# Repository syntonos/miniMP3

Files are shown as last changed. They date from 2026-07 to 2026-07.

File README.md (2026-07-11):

# miniMP3
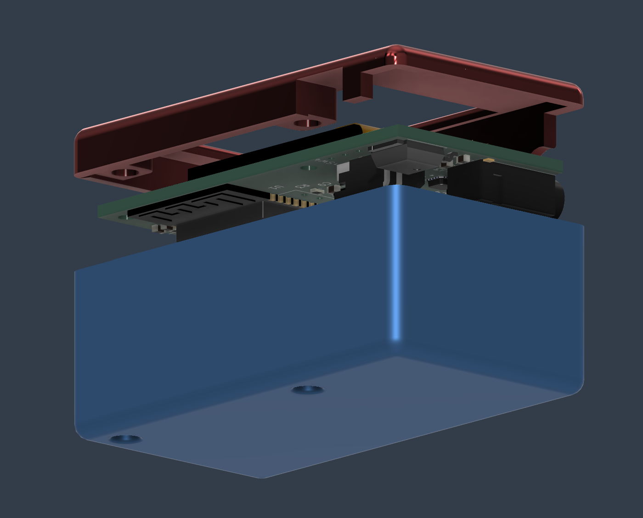
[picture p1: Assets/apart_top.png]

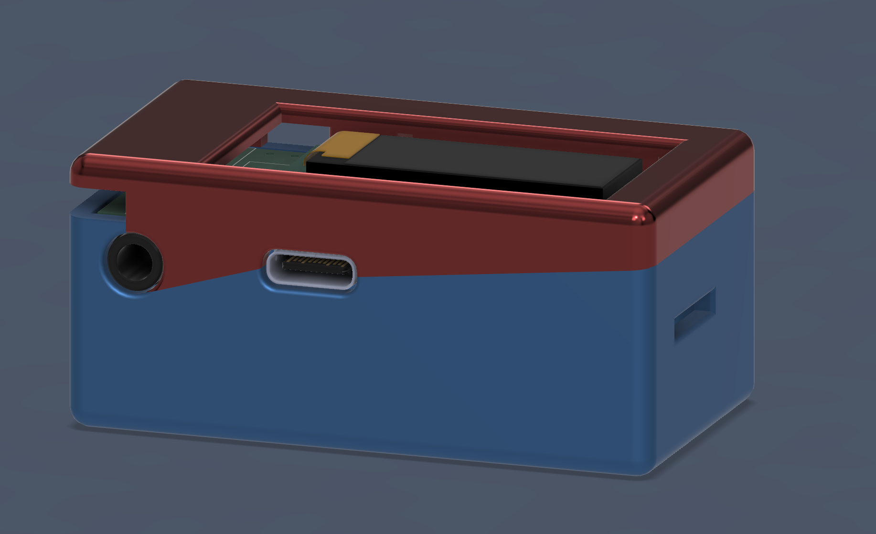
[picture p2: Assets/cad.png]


## About
A compact music player. 59.3 x 32 x 27 (mm). Bluetooth and 3.5mm jack compatible. mp3, wav, and flac compatible. 5-band EQ, and more functions when the firmware updates. 

## Idea
I wanted a little mp3 player that was small enough that I could just toss into my shirt pocket or keep it on a necklace. I don't want to be tied so much to my phone, and this seems like a reasonable first step to move a function off. There are also a couple old cds and etc. that I'd like to download.

## Assembly
Solder on:
- the display module
- the SD card module
- the boot switch (4x4 push switch)
- the power switch (toggle switch)
- the rotary switches

Plug in the LiPo Battery (JST-PH 2.0mm).

Insert the heat-sets into the two slots above and below. 


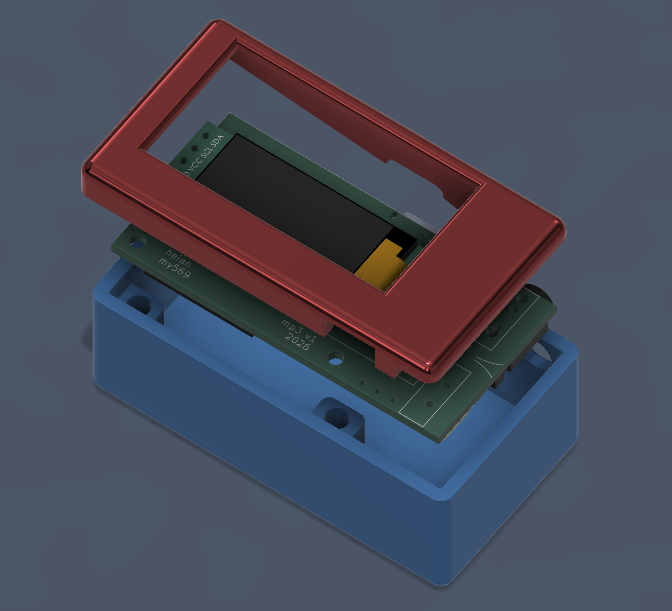
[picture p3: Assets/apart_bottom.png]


Fasten in the M2 screw on the bottom. 

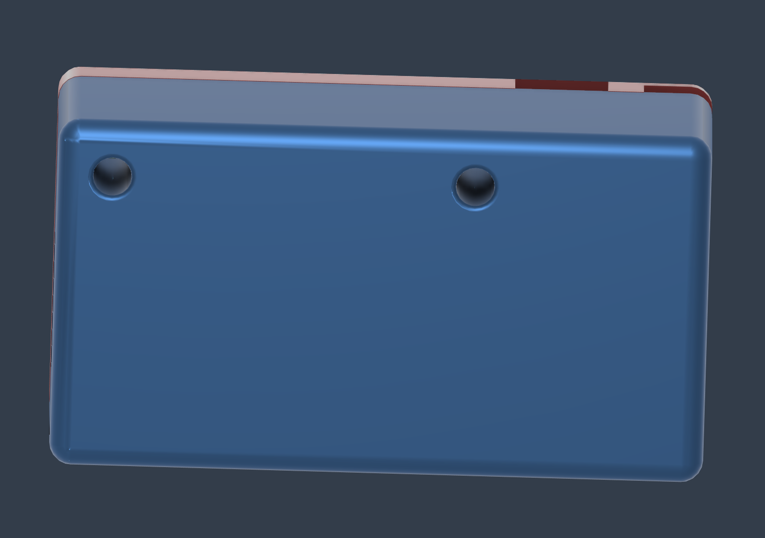
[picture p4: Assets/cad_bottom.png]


## PCB
### Layer 1 - Signal
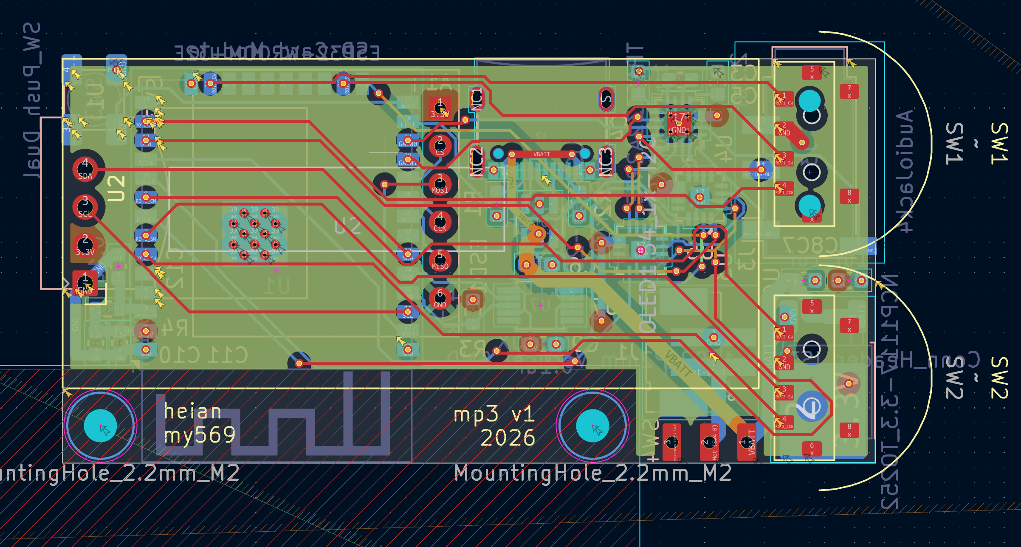
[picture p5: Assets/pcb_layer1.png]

### Layer 2 - GND
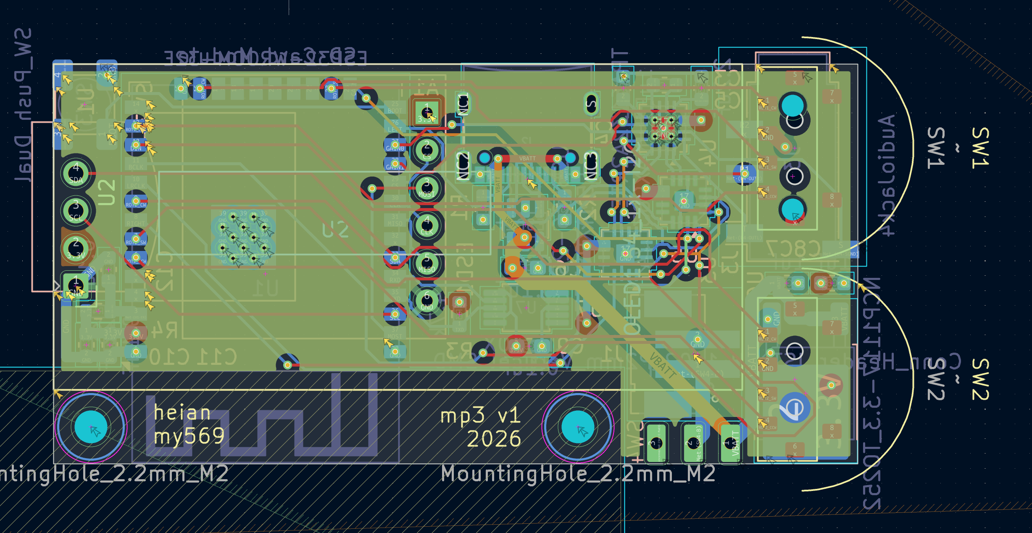
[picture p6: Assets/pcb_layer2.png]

### Layer 3 - Power
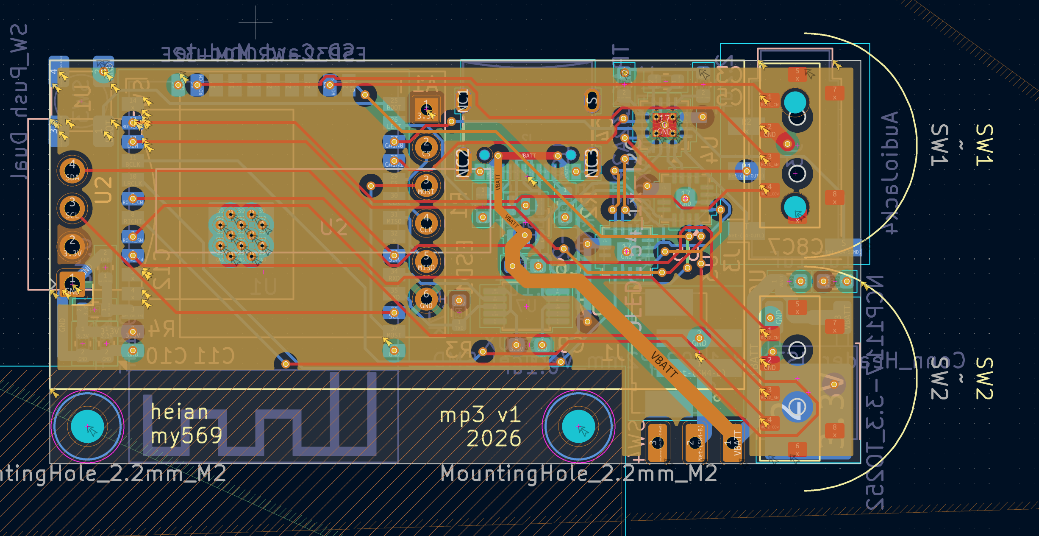
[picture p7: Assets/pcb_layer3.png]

### Layer 4 - Signal
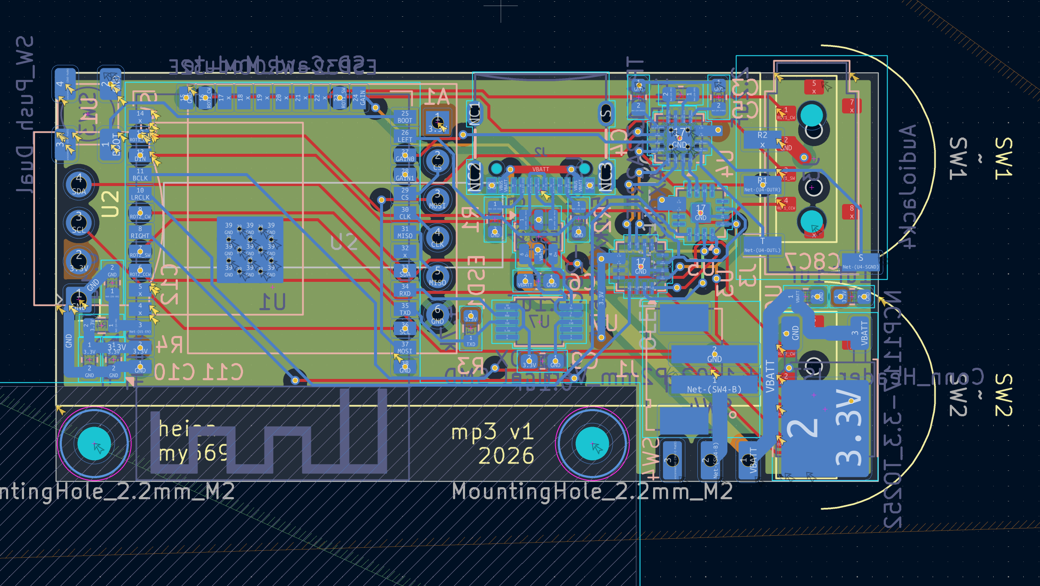
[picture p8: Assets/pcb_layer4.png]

### 3D Model Front
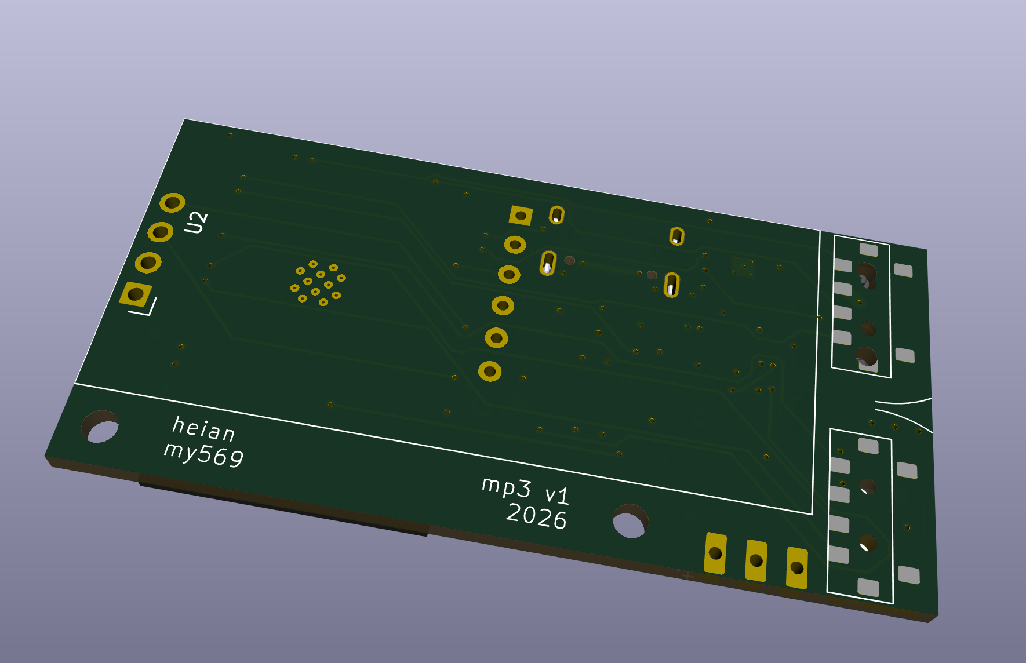
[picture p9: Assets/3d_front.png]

### 3D Model Back
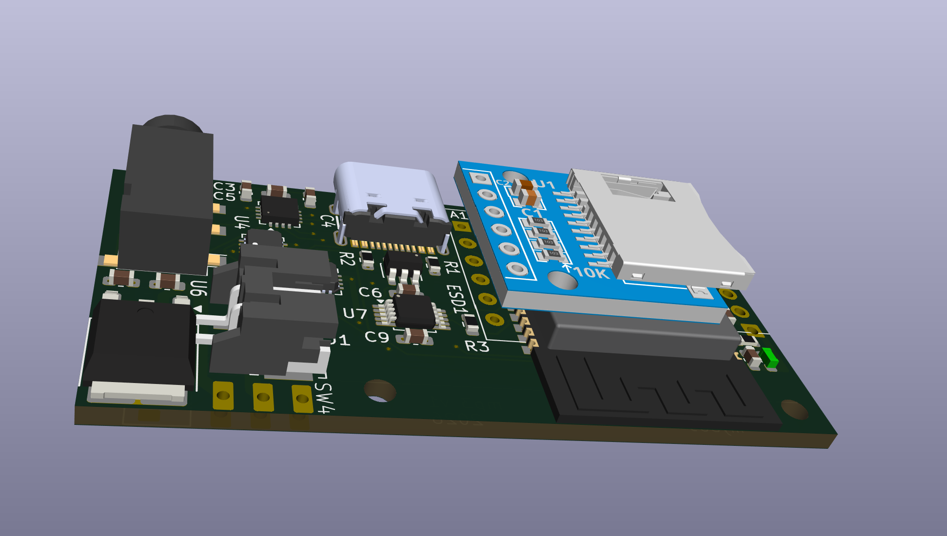
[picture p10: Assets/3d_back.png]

## Schematic
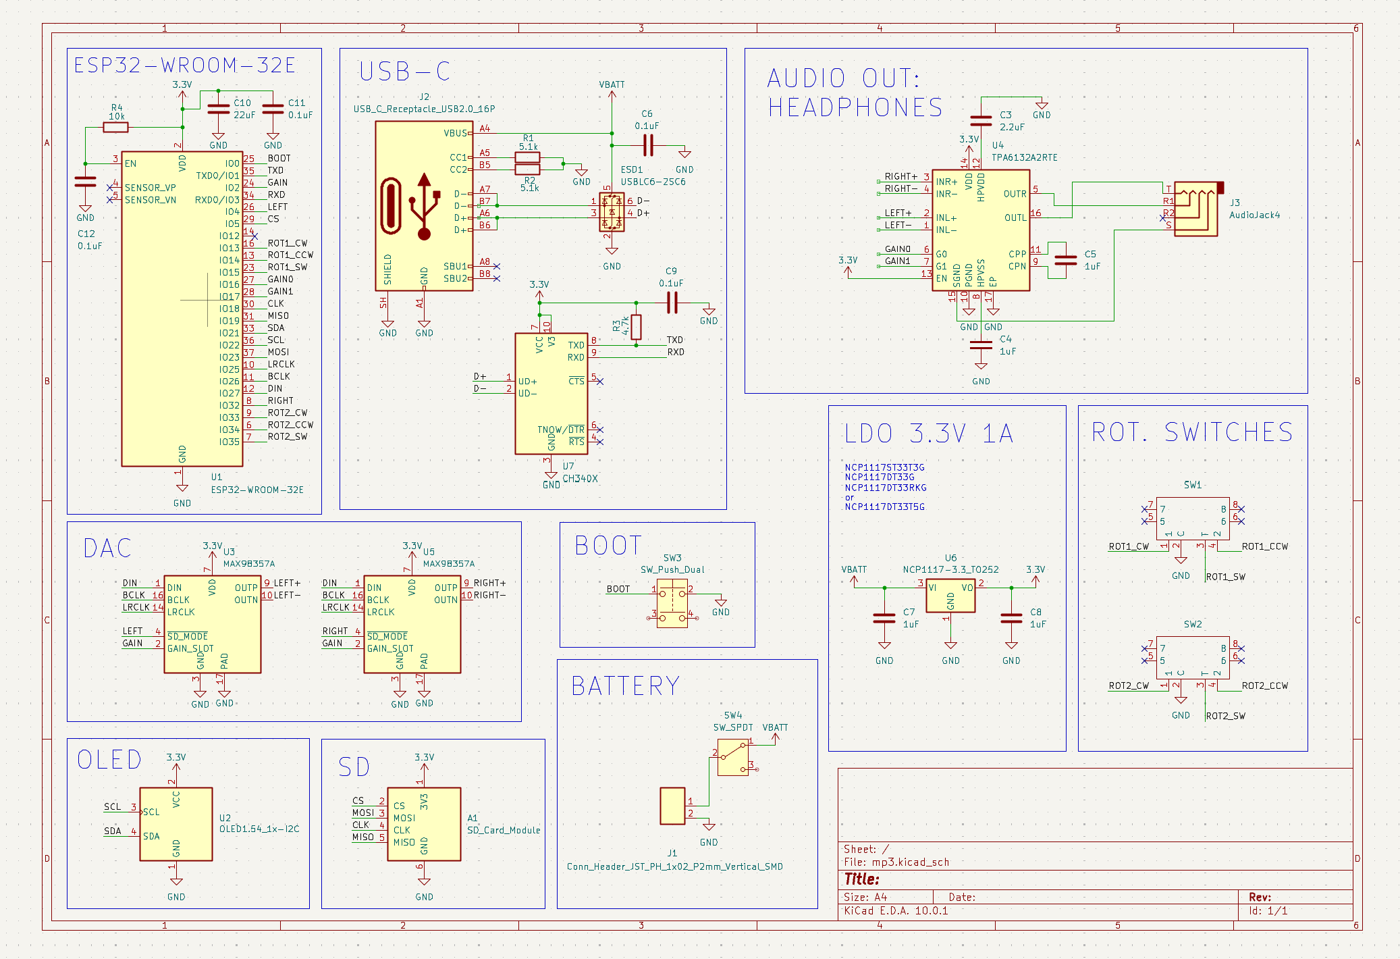
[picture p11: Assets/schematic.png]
 
## CAD

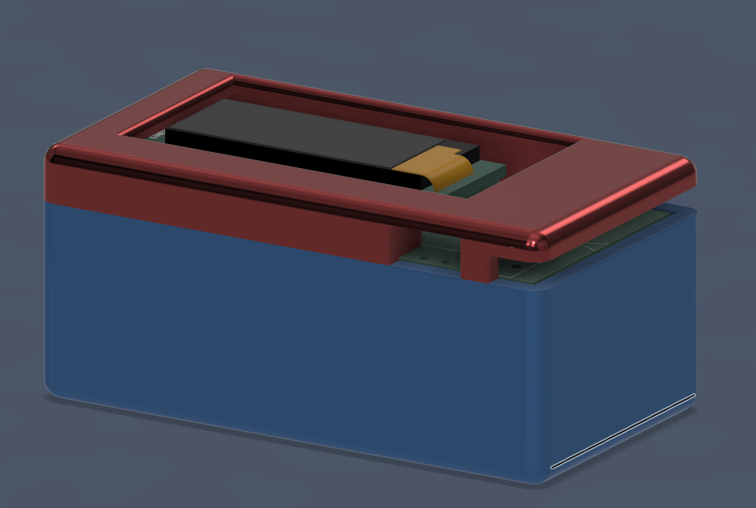
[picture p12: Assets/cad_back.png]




## BOM  
- 1x PCB 
- 1x SD Card Module
- 1x 1.54" OLED Display Module
- 1x PJ320-D Jack
- 1x 4mmx4mm Push Switch
- 1x Sliding Power Switch
- 2x M2 Heatset 3.5D 4.5H
- 2x M2 Heatset 3.5D 18H
- 2x M2 Screw 20H

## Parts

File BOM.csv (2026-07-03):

Description | Quantity | Cost Per Unit | Cost | Link | $52.83
SHOU HAN PJ-320D | 10 | $0.05 | $0.51 | https://www.lcsc.com/product-detail/C431535.html?s_z=n_q_PJ320D%2520
Micro SD Card Reader - USB-C | 1 | $4.13 | $4.13 | https://www.aliexpress.com/item/1005012224303053.html
Micro SD Card Module | 1 | $0.56 | $0.56 | Micro SD Storage Expansion Board Micro SD TF Card Memory Shield Module SPI For Arduino - AliExpress 502
1.54 Inch OLED Display 64×128 | 1 | $2.16 | $2.16 | https://www.aliexpress.com/item/1005007555150608.html
1000mAh LiPo | 1 | $19.00 | $19.00 | https://www.amazon.com/MakerHawk-Rechargeable-Protection-Connector-Electronic/dp/B0D9K7HQHT?sr=8-8
USBLC6-2SC6 | 10 | $0.04 | $0.41 | https://www.lcsc.com/product-detail/C2827654.html?s_z=n_q_USBLC6-2SC6
onsemi NCP1117ST33T3G | 5 | $0.24 | $1.18 | https://www.lcsc.com/product-detail/C26537.html?s_z=n_q_NCP1117ST33T3G
ESPRESSIF ESP32-WROOM-32E-N16 | 1 | $4.71 | $4.71 | https://www.lcsc.com/product-detail/C701343.html?s_z=n_q_ESP32-WROOM-32E
XUNPU QS-302-AGS8P | 2 | $0.38 | $0.76 | https://www.lcsc.com/product-detail/C42377854.html?s_z=n_q_t_thumbwheel | https://www.aliexpress.com/item/1005004291063132.html?scm_id=1007.14452.398466.0&scm-url=1007.14452.398466.0
CH340N | 1 | $0.65 | $0.65 | https://www.lcsc.com/product-detail/C2977777.html?s_z=n_q_ch340n
JST-PH 2mm 2-pin - 10pc | 1 | 1.72 | 1.72 | https://www.aliexpress.us/item/3256805806049470.html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
M2 Heatsinks - 3.5D 4.5L | 1 | 5.22 | 5.22 | https://www.aliexpress.us/item/3256806611972099.html?curPageLogUid=pmRS9OHkPpDI
M2 Heatsinks - 3.5D 10L | 1 | 7.96 | 7.96 | https://www.aliexpress.us/item/3256806611972099.html?curPageLogUid=pmRS9OHkPpDI
M2 Screws 20mm | 1 | 3.86 | 3.86 | https://www.aliexpress.us/item/3256801577619187.html?curPageLogUid=MdcYnRM4XBCg

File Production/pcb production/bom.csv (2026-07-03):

Designator | Footprint | Quantity | Value | LCSC Part #
C10 | 0603 | 1 | 22uF
C11, C12, C6, C9 | 0603 | 4 | 0.1uF
C3 | 0603 | 1 | 2.2uF
C4, C5, C7, C8 | 0603 | 4 | 1uF
ESD1 | SOT-23-6 | 1 | USBLC6-2SC6
J2 | USB-C_16 | 1 | USB_C_Receptacle_USB2.0_16P
R1, R2 | 0603 | 2 | 5.1k
R3 | 0603 | 1 | 4.7k
R4 | 0603 | 1 | 10k
SW1, SW2 | XUNPU QS-302-AGS8P | 2 | ~
U1 | ESP32-WROOM-32E | 1 | ESP32-WROOM-32E
U3, U5 | TQFN-16-1EP_3x3mm_P0.5mm_EP1.23x1.23mm | 2 | MAX98357A
U4 | WQFN-16-1EP_3x3mm_P0.5mm_EP1.6x1.6mm_ThermalVias | 1 | TPA6132A2RTE
U6 | TO-252-2 | 1 | NCP1117-3.3_TO252
U7 | MSOP-10_3x3mm_P0.5mm | 1 | CH340X

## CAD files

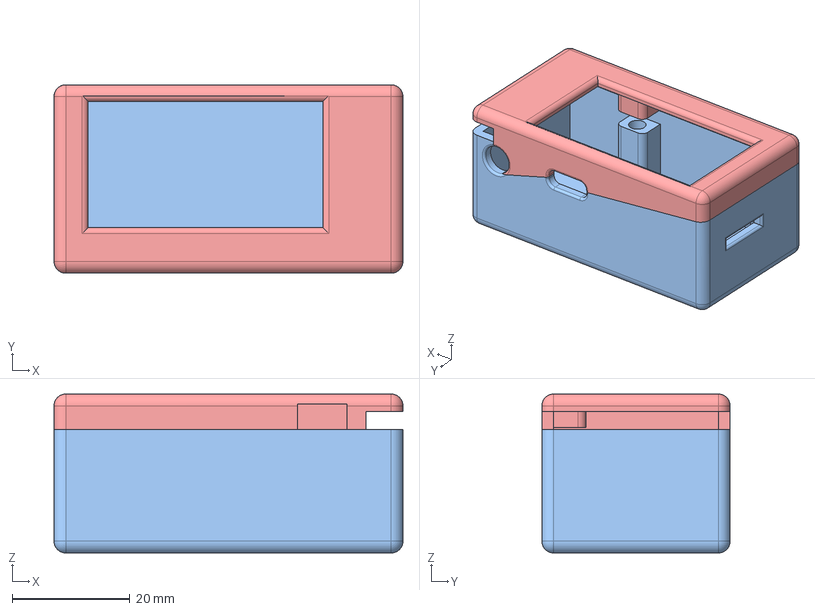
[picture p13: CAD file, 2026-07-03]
CAD/case.step
59.3 x 32.0 x 27.0 mm

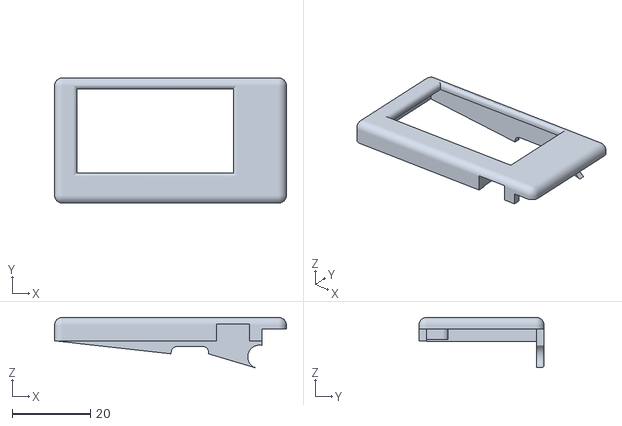
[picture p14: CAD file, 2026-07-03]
Production/top.stl
59.3 x 32.0 x 12.8

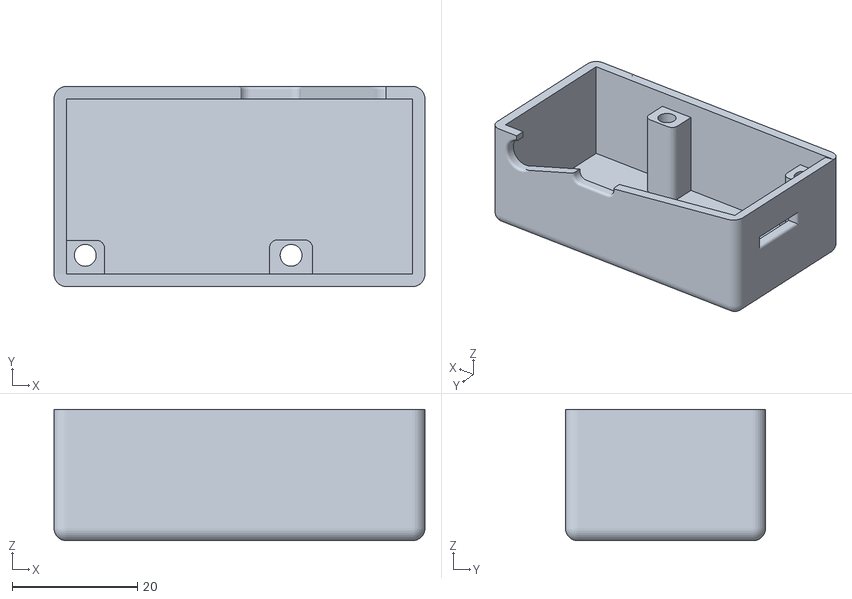
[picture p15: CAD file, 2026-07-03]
Production/bottom.stl
59.3 x 32.0 x 21.0

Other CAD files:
CAD/case_only.f3d

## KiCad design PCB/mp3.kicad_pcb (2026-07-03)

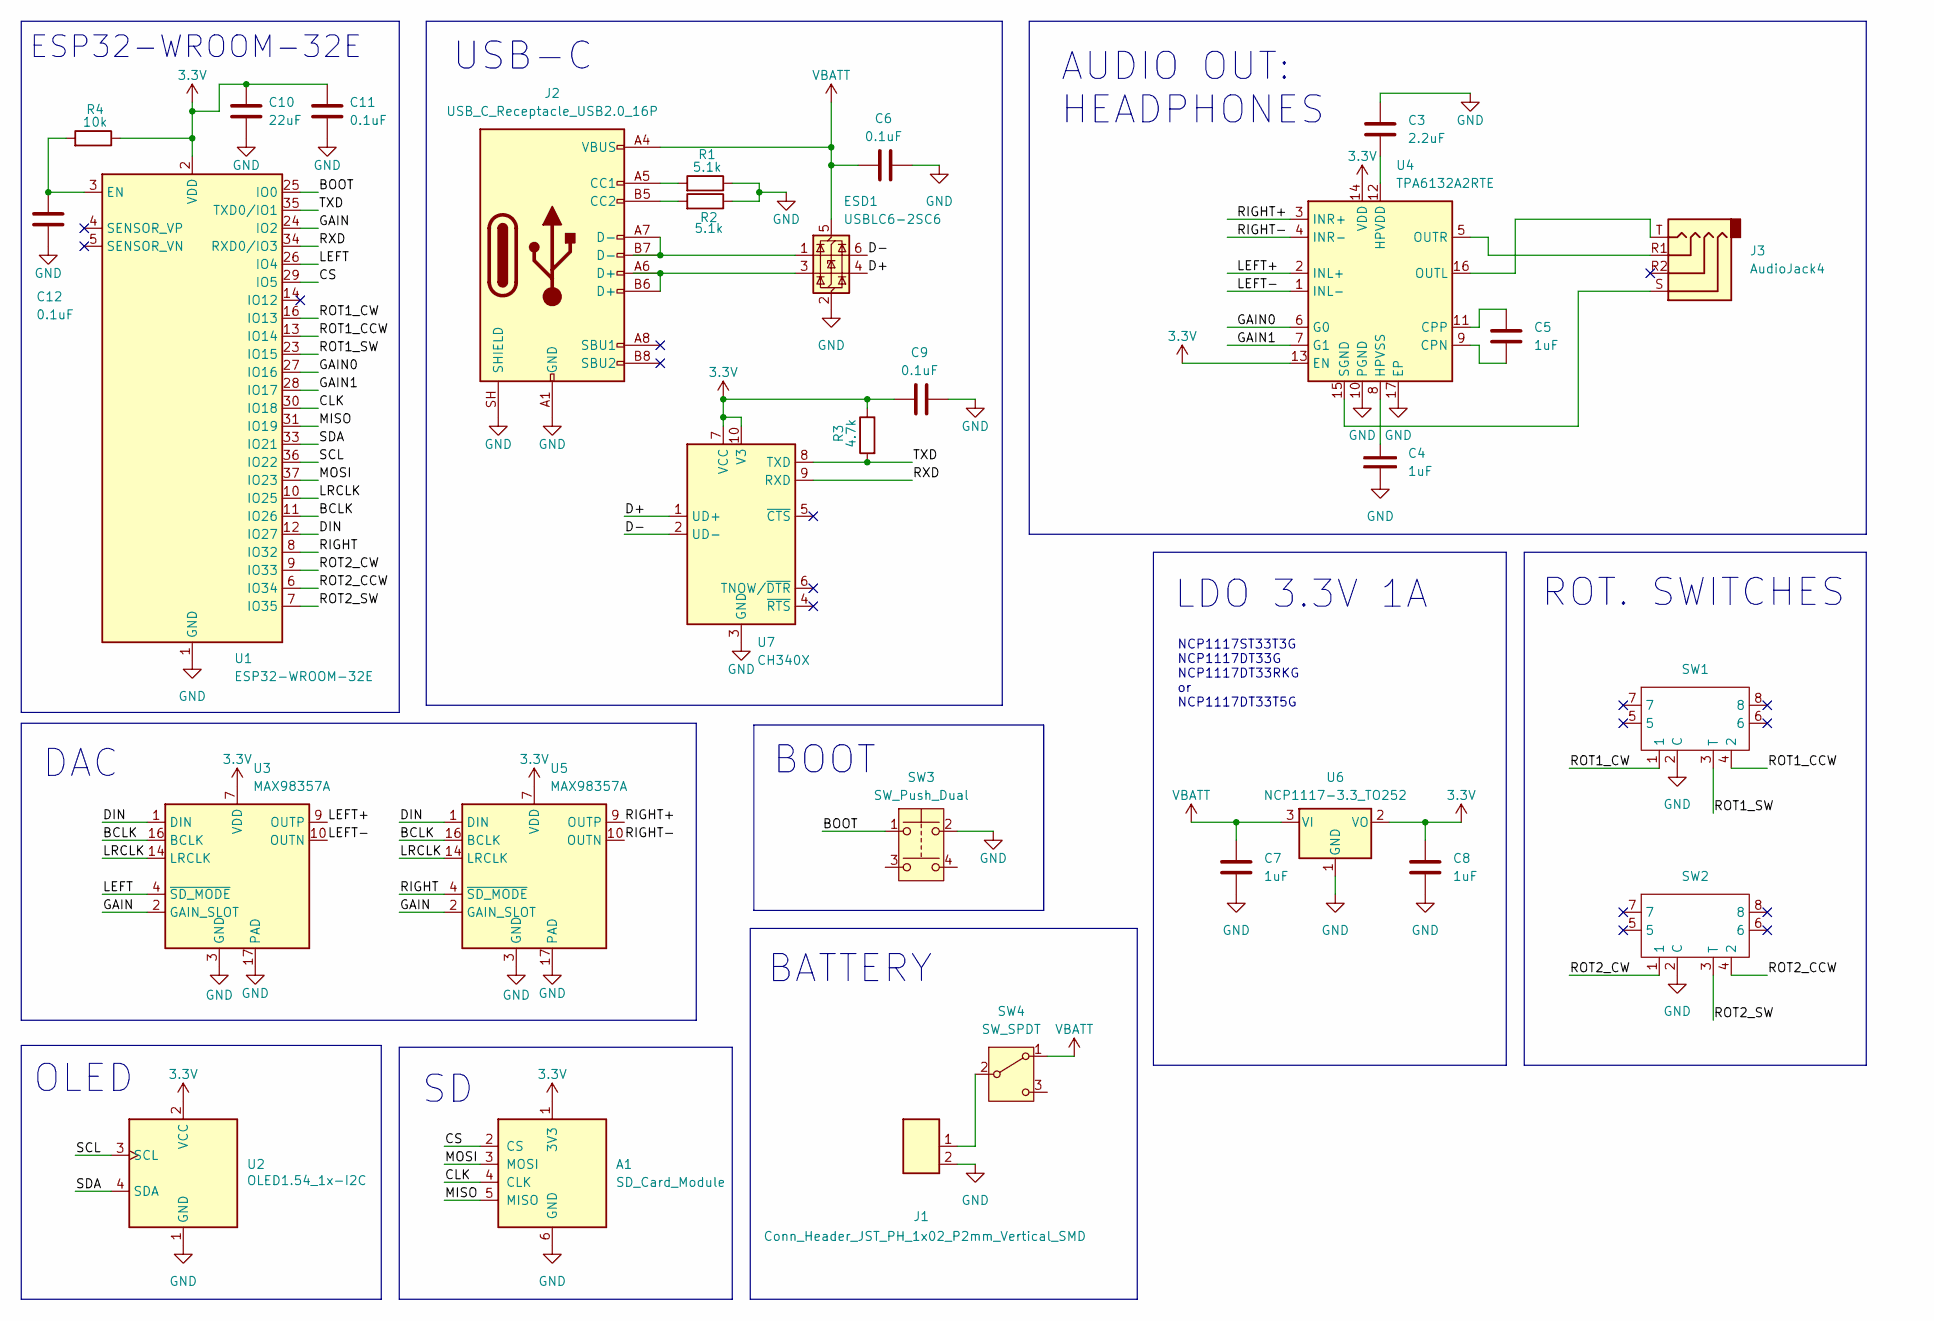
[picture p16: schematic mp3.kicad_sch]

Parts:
A1: SD_Card_Module
C3: 2.2uF; C_0603_1608Metric
C4, C5, C7, C8: 1uF; C_0603_1608Metric
C6, C9: 0.1uF; C_0603_1608Metric_Pad1.08x0.95mm_HandSolder
C10: 22uF; C_0603_1608Metric
C11, C12: 0.1uF; C_0603_1608Metric
ESD1: USBLC6-2SC6; SOT-23-6
J1: Conn_Header_JST_PH_1x02_P2mm_Vertical_SMD; Header_JST_PH_1x02_P2mm_Vertical_SMD
J2: USB_C_Receptacle_USB2.0_16P; USB-C_16
J3: AudioJack4; Jack_3.5mm_PJ320D_Horizontal_3D
R1, R2: 5.1k; R_0603_1608Metric
R3: 4.7k; R_0603_1608Metric
R4: 10k; R_0603_1608Metric
SW1, SW2: XUNPU QS-302-AGS8P
SW3: SW_Push_Dual; SW_Push_4x4mm
SW4: SW_SPDT; Untitled
U1: ESP32-WROOM-32E
U2: OLED1.54_1x-I2C; OLED 1.54in 4-pin Module
U3, U5: MAX98357A; TQFN-16-1EP_3x3mm_P0.5mm_EP1.23x1.23mm
U4: TPA6132A2RTE; WQFN-16-1EP_3x3mm_P0.5mm_EP1.6x1.6mm_ThermalVias
U6: NCP1117-3.3_TO252; TO-252-2
U7: CH340X; MSOP-10_3x3mm_P0.5mm

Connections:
3.3V: A1.1 (3V3), C8.1, C9.2, C10.1, C11.1, R3.2, R4.2, U1.2 (VDD), U2.2 (VCC), U3.7 (VDD), U3.8 (VDD), U4.13 (EN), U4.14 (VDD), U5.7 (VDD), U5.8 (VDD), U6.2 (VO), U7.7 (VCC), U7.10 (V3)
/BCLK: U1.11 (IO26), U3.16 (BCLK), U5.16 (BCLK)
/BOOT: SW3.1, U1.25 (IO0)
/CLK: A1.4 (CLK), U1.30 (IO18)
/CS: A1.2 (CS), U1.29 (IO5)
/D+: ESD1.4 (I/O2), U7.1 (UD+)
/D-: ESD1.6 (I/O1), U7.2 (UD-)
/DIN: U1.12 (IO27), U3.1 (DIN), U5.1 (DIN)
/GAIN: U1.24 (IO2), U3.2 (GAIN_SLOT), U5.2 (GAIN_SLOT)
/GAIN0: U1.27 (IO16), U4.6 (G0)
/GAIN1: U1.28 (IO17), U4.7 (G1)
/LEFT: U1.26 (IO4), U3.4 (~SD_MODE)
/LEFT+: U3.9 (OUTP), U4.2 (INL+)
/LEFT-: U3.10 (OUTN), U4.1 (INL-)
/LRCLK: U1.10 (IO25), U3.14 (LRCLK), U5.14 (LRCLK)
/MISO: A1.5 (MISO), U1.31 (IO19)
/MOSI: A1.3 (MOSI), U1.37 (IO23)
/RIGHT: U1.8 (IO32), U5.4 (~SD_MODE)
/RIGHT+: U4.3 (INR+), U5.9 (OUTP)
/RIGHT-: U4.4 (INR-), U5.10 (OUTN)
/ROT1_CCW: SW1.4 (2), U1.13 (IO14)
/ROT1_CW: SW1.1, U1.16 (IO13)
/ROT1_SW: SW1.3 (T), U1.23 (IO15)
/ROT2_CCW: SW2.4 (2), U1.6 (IO34)
/ROT2_CW: SW2.1, U1.9 (IO33)
/ROT2_SW: SW2.3 (T), U1.7 (IO35)
/RXD: U1.34 (RXD0/IO3), U7.9 (RXD)
/SCL: U1.36 (IO22), U2.3 (SCL)
/SDA: U1.33 (IO21), U2.4 (SDA)
/TXD: R3.1, U1.35 (TXD0/IO1), U7.8 (TXD)
GND: A1.6 (GND), C3.1, C4.1, C6.1, C7.2, C8.2, C9.1, C10.2, C11.2, C12.2, ESD1.2 (GND), J1.2, J2.A1 (GND), J2.A12 (GND), J2.B1 (GND), J2.B12 (GND), J2.GND, J2.SH (SHIELD), R1.2, R2.2, SW1.2 (C), SW2.2 (C), SW3.2, U1.1 (GND), U1.15 (GND), U1.38 (GND), U1.39 (GND), U2.1 (GND), U3.3 (GND), U3.11 (GND), U3.15 (GND), U3.17 (PAD), U4.10 (PGND), U4.17 (EP), U5.3 (GND), U5.11 (GND), U5.15 (GND), U5.17 (PAD), U6.1 (GND), U7.3 (GND)
unnamed: ESD1.1 (I/O1), J2.A7 (D-), J2.B7 (D-)
unnamed: ESD1.3 (I/O2), J2.A6 (D+), J2.B6 (D+)
unnamed: J2.A5 (CC1), R1.1
unnamed: J2.B5 (CC2), R2.1
unnamed: J1.1, SW4.2 (B)
unnamed: C12.1, R4.1, U1.3 (EN)
unnamed: C5.2, U4.9 (CPN)
unnamed: C5.1, U4.11 (CPP)
unnamed: C3.2, U4.12 (HPVDD)
unnamed: C4.2, U4.8 (HPVSS)
unnamed: J3.T, U4.16 (OUTL)
unnamed: J3.R1, U4.5 (OUTR)
unnamed: J3.S, U4.15 (SGND)
VBATT: C6.2, C7.1, ESD1.5 (VBUS), J2.A4 (VBUS), J2.A9 (VBUS), J2.B4 (VBUS), J2.B9 (VBUS), J2.VBUS, SW4.1 (A), U6.3 (VI)

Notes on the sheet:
DAC
NCP1117ST33T3G NCP1117DT33G NCP1117DT33RKG or NCP1117DT33T5G
ESP32-WROOM-32E
BATTERY
USB-C
LDO 3.3V 1A
OLED
BOOT
ROT. SWITCHES
AUDIO OUT: HEADPHONES

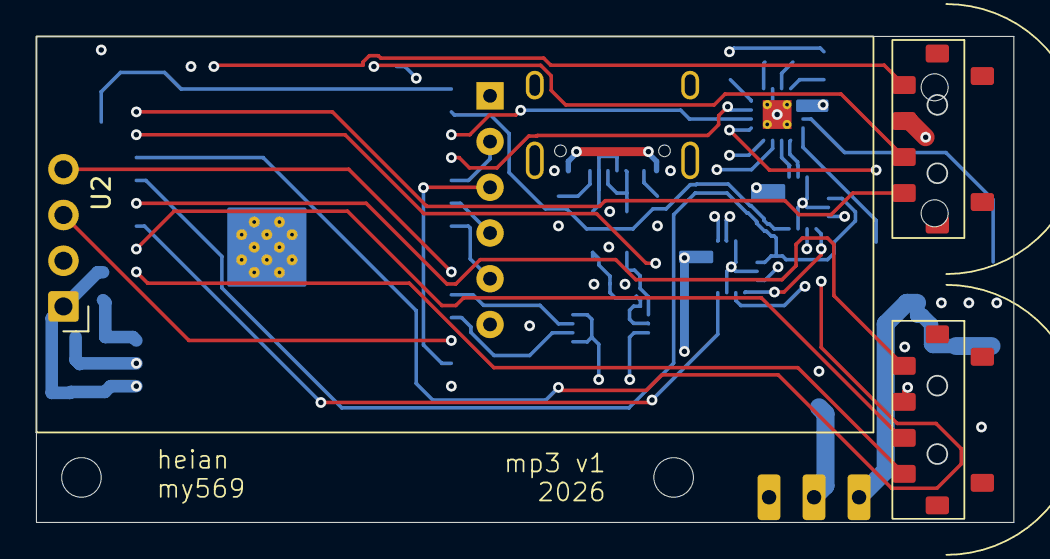
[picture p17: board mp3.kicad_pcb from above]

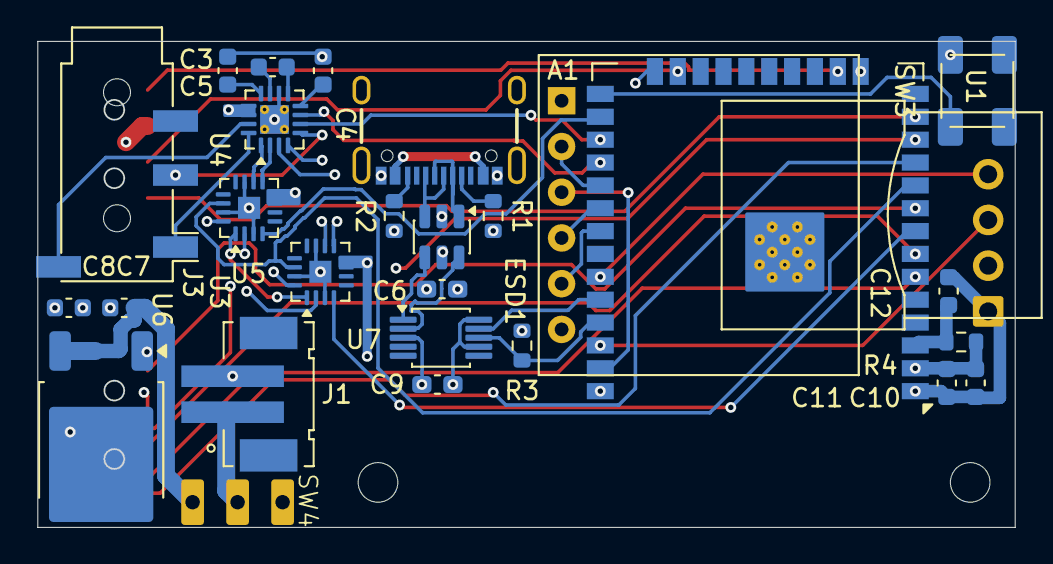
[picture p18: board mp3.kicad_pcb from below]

Board: 4 copper layers, 54.3 x 27.0 mm, 32 parts (27 on the bottom side), 45 nets.

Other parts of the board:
M1, M2: MountingHole_2.2mm_M2

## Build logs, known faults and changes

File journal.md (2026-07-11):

# log #1: laying out the schematic
so i want this to have as small a footprint as possible for it to be maximally portable. this session was mostly about trying to figure out how to do that. 


this seems to be what's minimally viable. well i need to add a 3v3 buck boost. 




i don't think it can stay this small ! but hoping

# log #2: changed footprint


mostly just figuring out how to further compact this. i've decided on two thumbwheel rotary encoders instead of the original controls. they have the advantage of being surface mount, so i can fit components on the back. 

i might swap out the OLED for a 1.5" instead. i feel like this one might actually be too small, and the pin placement is genuinely inconvenient.

# log #3: worked on schematic and changed footprint again.


finished laying out the schematic! only thing left to do is to check the esp32-wroom-32 datasheet and figure out how to connect all the gpios. 



this seems to be the final arrangement for the pcb. i'm fairly happy with how compact it's going to be. i'm going to add a few mounting holes to the pcb. i will be making a 3d printed enclosure but i'm planning for the final thing to have a case made of acrylic panels

# log #4: finding rotary switches that actually work
so my previous rotary switches did not work! they don't have a push switch, which is fairly necessary. so back to the trenches (lcsc)



this part seems to work. 



i made a kicad symbol. 



and a footprint!



now i have this as the hopefully final arrangement

# log #5:  routing ESP32-WROOM-32E pins
a lot of cross referencing datasheets on this one. 

also apparently the esp32-wroom-32e does not have usb support ! so i need a new ic that converts the d+ d- differential pair to to uart transmission. 



i basically had just enough pins for this to work. 



put them into the firmware before i forget!

i also need two more switches. one tactile one for boot and one latching one for disconnecting the battery and turning on and off the mp3 player. 



placed down most of the components... oh no. i can sort of already tell this is going to be a nightmare to wire. and i'm still going to have to find space for the two push switches...

# log #6: started wiring...


made a footprint for the boot switch and the power switch. 




should be fine?? worst come to worst i have to use wires



well this is a minor nightmare. i'll figure it out though
# log #7: wiring done !

well this seems like a bad idea. it was generally impossible to wire it any other way. unless i'm using like four vias per wiring. 


done???? oh god i'm not looking forward to doing design check. 


there used to be way more but c'est la vie. 


ok got rid of the errors. i'm probably just going to have to leave the warnings because they're just stuff about silkscreen getting clipped, and i can't help that because there's physically no space. 

well this was a horrifying board. if it works it will be a minor miracle. 



# log #8: oh boy pcba is expensive (assembling bom)


so apparently the esp32-wroom-32e makes this a standard assembly... which is fun. i love that. so this is a little more expensive than i had hoped. but still cheaper than an mp3 player on the market 



also apparently pick and place is a little bad when it comes to parts, and it doesn't really specify orientation, so minor wrangling had to happen. i've finally realized what the little silkscreen and the little dot on ics is for !



again aliexpress is 66% shipping costs .... always fun. i do get why shipping to taiwan is so expensive in a political sense but really geographically this should be easy

and highkey i cannot get lipos that ship to taiwan in aliexpress. so i'm using amazon for this one part. 



ig i'll do the programming and testing while it's attached to my computer? which isn't the worst thing in the world

# log #9: oops back to wiring


so as i was making the case, i did section analysis to get the ports and i realized that i've set the ports way too far in while making the pcb. so back to wiring... 

honestly this is probably good, because it give me the chance to fix some fixes now that i have the power of hindsight on my side. and a little more space now that the jacks are moved up

for example: 

this absolute nightmare of a situation


actually not that bad with a little more space and planning. 


got everything routed up this time without using any signals in the gnd or power plane



# log #10: cad done

it's donee. actually it's almost done. i just need to divide it into the top and bottom so that it actually makes sense. (the heatsets on either side of the pcb, combining around the ports so that things don't jam horribly)


ok so i had to get rid of all the fileting to start separating


this is how i want the split and now i just need to figure out how to do it. 

ok so apparently this is an absolute nightmare and there are no tools in fusion360 that will just do it. this was after two hours of research . 
- main problem: the dividing line looks different on different sides of the object. so a lot of the tools that requires the same height or the same plane don't work. plus i don't want to lose any volume so some other tools are off the table. 


my awful solution is to split it into three parts first. then divide the above bit 

and recombine the pieces into a top and bottom half. 

top: 
bottom: 




done!

# log #11: more pcb + bom nonsense


ok so i did change up the pcb a little bit so i need to do this process again. again pick and place is my sworn enemy. and i still don't know why esp32s are standard assembly

so shipping to the usa is scarily expensive, so i'm probably just going to ship to taiwan



so shipping is still the bulk of the cost, which is always fun

# log #12: wrangling bom

so i've managed to get the aliexpress thing down to a reasonable amount. aliexpress is just incredibly annoying because i haven't used up the welcome deal thing on this account, so i just need to avoid those items because it just teleports me to another screen. this does seem like the absolute minimum i could get the bom tho. a lot of this is just because i don't have supplies while i'm here. 

the main gate on this is just that the pcba is so expensive, and the second I stop being in taiwan, the shipping and tariff costs go up by so much. so this is really time gated by quite a few things.

also did a lot of minor fixes on the pcb. didn't change the outline so i think i'm fine on not changing the step

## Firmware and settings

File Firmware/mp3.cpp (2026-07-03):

//I2S
#define DIN 27
#define LRCLK 25
#define BCLK 26
#define LEFT 4
#define RIGHT 32
#define GAIN 2
#define GAIN0 16
#define GAIN1 17

//I2C
#define SDA 21
#define SCL 22

//SD (SPI)
#define CS 5
#define MOSI 23
#define MISO 19
#define CLK 18

//UART
#define TXD 1
#define RXD 3

//BOOT
#define BOOT 0  

//Rotary Encoder (MENU)
#define UP 14
#define DOWN 13
#define SELECT 15

//Rotary Encoder (VOLUME)
#define VOLUME_UP 34
#define VOLUME_DOWN 33
#define VOLUME_SELECT 35

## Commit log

2026-07-03 all files in
    [BOM.csv, bom.csv, bottom.stl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]
2026-08-04 soldering instructions, firmware instructions, readme changes
2026-08-04 modded BOM a little
2026-08-07 modded readme - BOM expanded
